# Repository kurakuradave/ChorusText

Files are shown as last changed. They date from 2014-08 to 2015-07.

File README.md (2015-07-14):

ChorusText
==========

What is ChorusText?
ChorusText is a text editor. But it's a special kind of text editor, the user doesn't need to have eyesight to do text editing using ChorusText. 

On the surface of the device, there are three physical sliders  that the user can reach out to at any time.

Changing the position of the slider would cause the system to pull out the corresponding part of the text and speaks the content out loud, using text-to-speech.

So changing the position of the line slider's knob from top to bottom will result in the system reading the text progressively line by line.

And changing the position of the word slider knob from left to right will result in the system reading the words in the current line, progressively word by word.

And likewise, changing the position of the character slider knob from left to right will result in the system spelling the letters of the current word, in the current line, progressively letter by letter.

This way, the user can read the text he's working on with ease, and can drill down to the level of characters effortlessly, for example, when spell-checking.

Furthermore, as the user types, the sliders continuously reposition themselves to physically manifest the latest state of the text and where the user is in the text.

If he adds two more characters to the current word, the character slider would move two steps to the right.
 If he adds three words to the line, the word slider would move three steps to the right.
Deleting the current line would make the line slider to move one step up, and so on.

The cursor is no longer an abstract blinking thing, that only lives inside the monitor, where the only way to locate its position is by means of eyesight. 

It is now physically manifested by the three sliders.

Simply reach out to the sliders with your hand and listen, the text is immediately accessible and navigable – no eyesight required.

Installing Node.js on pcDuino / Raspberry Pi
--------------------------------------------

1. On the pcDuino (or the Pi), open the terminal and execute:
$ wget http://nodejs.org/dist/v0.10.24/node-v0.10.24-linux-arm-pi.tar.gz
$ tar -xzvf node-v0.10.24-linux-arm-pi.tar-gz
$ sudo mv node-v0.10.24-linux-arm-pi /opt/node/

2. After that, test Node.js by:
$ /opt/node/bin/node
And if everything's okay, you'll get a ">" prompt. Simply hit Ctrl+C to quit.

Nodejs.org provides built binaries for the Raspberry Pi, which also works with pcDuino v1 or pcDuino3. There's no need to compile from source anymore, we simply need to download, extract and place it in a good location (in this case /opt/node/)
ChorusText is currently developed on Node version v0.10.24.

Chorus Text Client
------------------
1. Connect the pcDuino/Raspberry Pi to your wifi network and plug the Arduino to the pcDuino/Pi's USB port
2. SSH into the pcDuino/Pi, navigate to ChorusTextClient/ folder and execute: 
   $ sudo /opt/node/bin/node ChorusTextClient.js
3. Access the device by opening a web browser in any machine connected to the same wifi network as the pcDuino/Pi, and then go to it's hostname and at port 3000. For example: "http://pcduinobox:3000/" if the hostname for the SBC is pcduinobox ( or try its full IP if it doesnt work ).
4. To import text, go to http://pcduinobox:3000/import
5. To read text, go to http://pcduinobox:3000/read
6. To adjust settings, go to http://pcduinobox:3000/settings
7. To type, make sure the terminal window from which you launched the ChorusTextClient.js with node is in focus before you start typing. It is tied to the standard input on that terminal window so if the window is out of focus, ChorusTextClient can't pick up the keystrokes.

Repository Structure
--------------------

* Code for the Arduino is located in /arduino/
* Code for node client is located in /ChorusTextClient/
* Code for node server is located in /node-server/ (not yet)
* Hardware related items such as laser-cutting design files, wiring guide, list of components used, datasheets, etc are located in /hardware/

Got Questions?
--------------

Don't hesitate to email me :)

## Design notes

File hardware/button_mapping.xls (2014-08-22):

BUTTON MAPPING – ChorusText Board v0.17082014
BIN | LINE | WORD | CHAR | DEC
1 | Go Top | Go Top | Go Top | 1
10 | Scroll Up | Scroll Up | Scroll Up | 2
100 | Scroll Down | Scroll Down | Scroll Down | 4
1000 | Go Botto | Go Botto | Go Botto | 8
10000 | NA | FringeTop | DialLeft | 16
100000 | NA | FringeBottom | DialRight | 32
1000000 | NA | NA | NA | 64
10000000 | NA | NA | NA | 128

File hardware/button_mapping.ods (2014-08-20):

BUTTON MAPPING – ChorusText Board v0.17082014
BIN | LINE | WORD | CHAR | DEC
1 | Go Top | Go Bottom | Go Bottom | 1
10 | Scroll Up | Scroll Down | Scroll Down | 2
100 | Scroll Down | Scroll Up | Scroll Up | 4
1000 | Go Botto | Go Top | Go Top | 8
10000 | NA | FringeTop | DialLeft | 16
100000 | NA | FringeBottom | DialRight | 32
1000000 | NA | NA | NA | 64
10000000 | NA | NA | NA | 128

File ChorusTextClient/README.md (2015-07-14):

# ChorusTextClient

ChorusTextClient is the app to launch on the device. It is a Node.js application that handles communication with the Arduino, listens for keyboard keypresses, initiates text-to-speech, and serves the web-interface ( for text import, reading and settings ).

To run:
$ sudo /opt/node/bin/node ChorusTextClient.js

Replace the path to node according to your system, sudo is needed for the Arduino communication.

## Diagram
```

+-------------------------------------------------------------------+         +-------------------+
| ChorusText Device ( Client )                                      |         | ChorusText Server | 
|                                                                   |         |                   |
|               +-------------------------------------------------+ |         |  ( Coming Soon )  |
|               |  pcDuino                                        | |         |                   |
|               |                                                 | |         +-------------------+
|               |  +-----------------+                            | |
|               |  | ChorusSpeech.js |                            | |
|               |  |                 |                            | |
|               |  | spawn Text-to-  |                            | |
|               |  | speech child    |                            | |          
|               |  | processes       |                            | |          
|               |  +-----------------+                            | |          
|               |           |                                     | |         
|   /-------\   |  +-------------------+       +---------------+  | |          
|   |Arduino|   |  |ChorusTextClient.js|-------| Web Interface |  | |          
|   |       <---+-->                   |       |               |  | |
|   |sensors|   |  | main app          |___    | serves pages: |  | |     +------------------------+
|   |motors |   |  +-------------------+   \   | import, read, <--+-+--+  |  Tablet/Phone/Desktop  |
|   \-------/   |           |              |   | settings      |  | |  |  |                        | 
|               |  +-------------------+   |   +---------------+  | |  +--> Web-browser            |
|               |  | ChorusDocument.js |   |                      | |     |                        |
|               |  |                   |   |  +-----------------+ | |  +--> Other apps (Orca/iBus) |
|               |  | updates:          |   \__| API for Text    <-+-+--+  +------------------------+
|               |  | text content      |      | Import / Export | | |
|               |  | cursor position   |      +-----------------+ | |
|               |  +-------------------+                          | |
|               |                                                 | |
|               +-------------------------------------------------+ |
|                                                                   |
+-------------------------------------------------------------------+

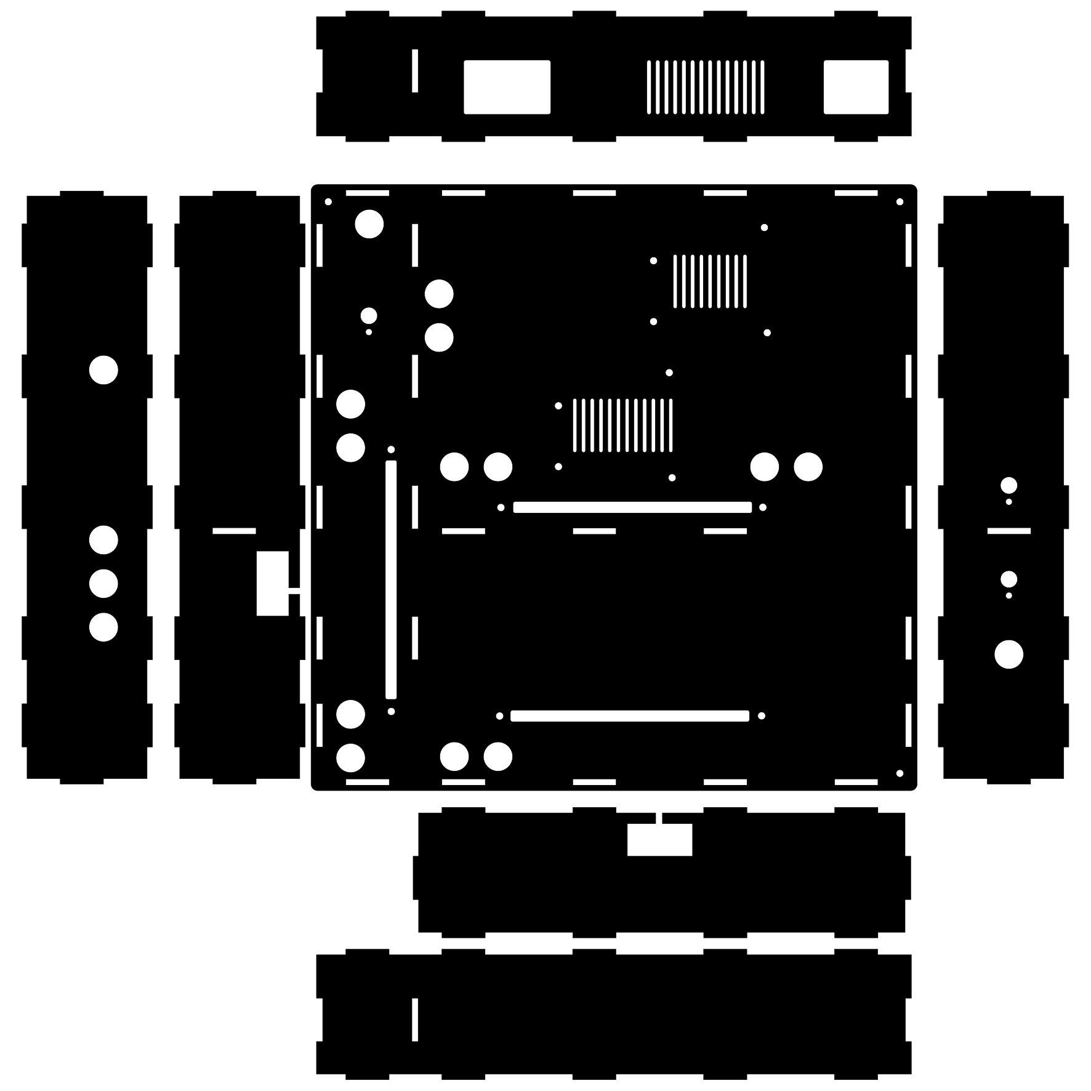
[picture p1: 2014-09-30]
hardware/board-design/panelmount-buttons/more_features_coming.png

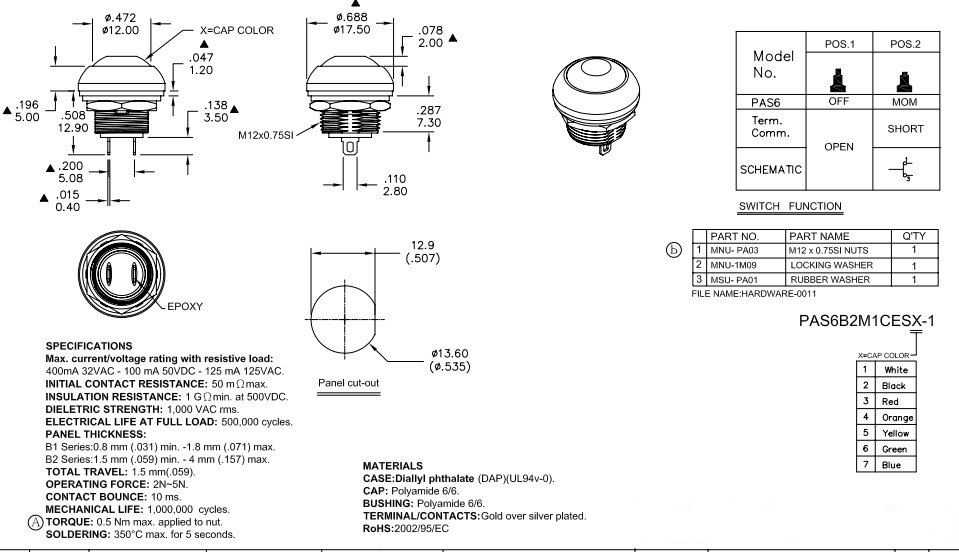
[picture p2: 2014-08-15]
hardware/ref/12mm Domed Push Button Pack.jpg

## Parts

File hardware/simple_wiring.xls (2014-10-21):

No | COMPONENT | CONNECTOR | CONNECT_TO
1 | Line Slide Potentiometer | 1 | Arduino GND pin
 |  | 2 | Arduino A0 pin
 |  | 3 | Arduino 5V pin
 |  | 1' | not used
 |  | 2' | not used
 |  | 3' | not used
 |  | T | not used
 |  | A | MotorShield MotorPort 1, INNER screw terminal
 |  | B | MotorShield MotorPort 1, OUTER screw terminal
2 | Word Slide Potentiometer | 1 | Arduino GND pin
 |  | 2 | Arduino A1 pin
 |  | 3 | Arduino 5V pin
 |  | 1' | not used
 |  | 2' | not used
 |  | 3' | not used
 |  | T | not used
 |  | A | MotorShield MotorPort 2,INNER screw terminal
 |  | B | MotorShield MotorPort 2,OUTER screw terminal
3 | Char Slide Potentiometer | 1 | Arduino GND pin
 |  | 2 | Arduino A2 pin
 |  | 3 | Arduino 5V pin
 |  | 1' | not used
 |  | 2' | not used
 |  | 3' | not used
 |  | T | not used
 |  | A | MotorShield MotorPort 3,INNER screw terminal
 |  | B | MotorShield MotorPort 3,OUTER screw terminal
4 | Focus Dial | left connector | Arduino 5V pin
 | Orient the motorized rotary | center connector | Arduino A3 pin
 | potentiometer like so: | right connector | Arduino GND pin
 | - rotating rod facing up | left motor terminal | Motor Shield MotorPort4, OUTER screw terminal
 | - motor facing down | right motor terminal | Motor Shield MotorPort 4, INNER screw terminal
 | - six connectors facing you

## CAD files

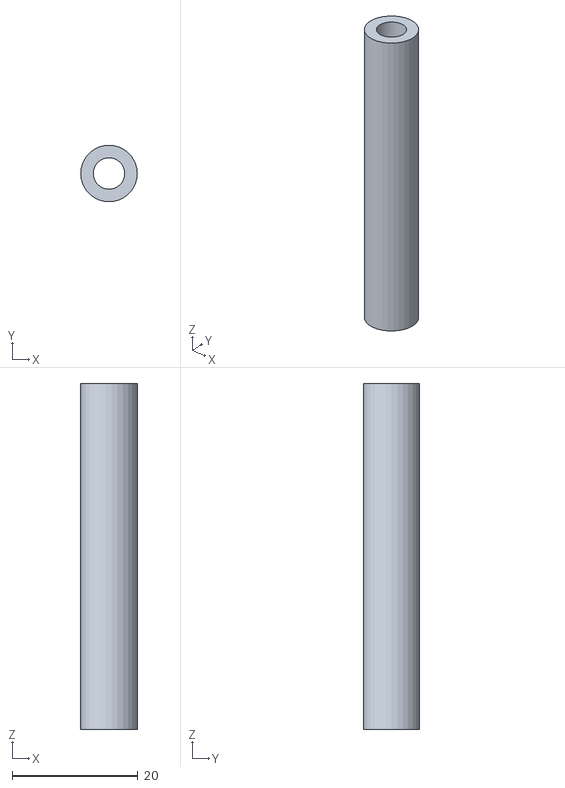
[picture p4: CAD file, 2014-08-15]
hardware/3Dprinting/tubeA.stl
9.00 x 8.95 x 55.0

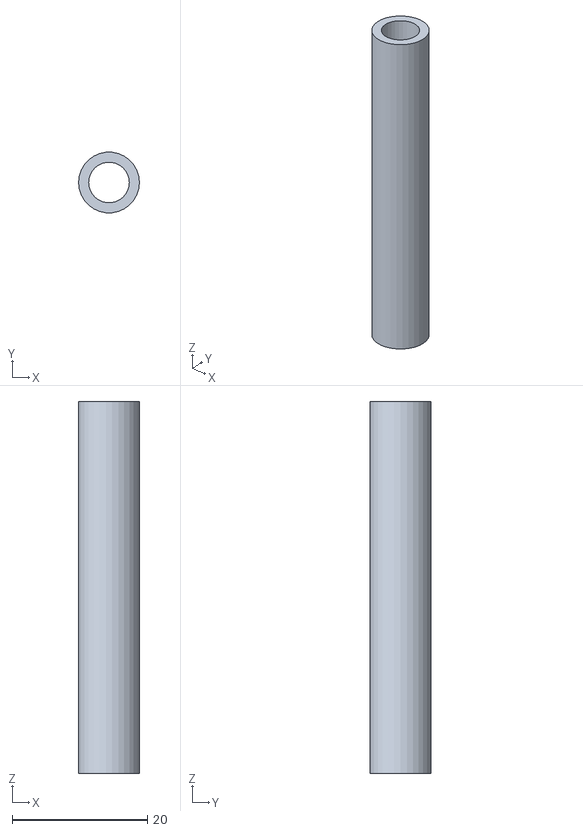
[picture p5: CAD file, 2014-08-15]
hardware/3Dprinting/tubeB.stl
9.00 x 8.95 x 55.0

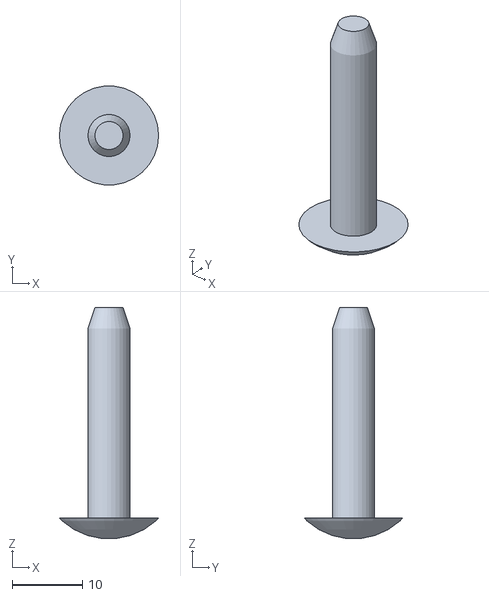
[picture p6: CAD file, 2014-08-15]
hardware/3Dprinting/spokeB.stl
14.2 x 14.1 x 32.9

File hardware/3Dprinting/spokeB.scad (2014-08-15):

$fn=30;

translate([0,0,26]) {
	cylinder(3,3,2);
}

translate([0,0,-2]) {
    cylinder(r=3,h=28);
}

translate( [0,0,6] ) {
	difference() {
  		  sphere( r=10 );
    		translate([0,0,-7]){
      	  cylinder(r=15,h=17); 
    		}
	}
}

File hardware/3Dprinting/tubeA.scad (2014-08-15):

$fn=30;
difference() {
    cylinder( r=4.5, h=55 );
    cylinder( r=2.5, h=60);
};

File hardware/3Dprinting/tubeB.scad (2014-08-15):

$fn=30;
difference() {
    cylinder( r=4.5, h=55 );
    cylinder( r=3, h=60);
};

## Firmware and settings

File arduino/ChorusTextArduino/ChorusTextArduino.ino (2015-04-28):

/*-----------------------------------------------------------------------------\
|                                                                              |
|    ChorusTextArduino - Arduino program for ChorusText Open Assistive Device  |
|    Copyright (C) 2014  David Effendi                                         |
|    email: kurakuradave@gmail.com                                             |
|                                                                              |
|    This program is free software: you can redistribute it and/or modify      |
|    it under the terms of the GNU General Public License as published by      |
|    the Free Software Foundation, either version 3 of the License, or         |
|    (at your option) any later version.                                       |
|                                                                              |
|    This program is distributed in the hope that it will be useful,           |
|    but WITHOUT ANY WARRANTY; without even the implied warranty of            |
|    MERCHANTABILITY or FITNESS FOR A PARTICULAR PURPOSE.  See the             |
|    GNU General Public License for more details.                              |
|                                                                              |
|    You should have received a copy of the GNU General Public License         |
|    along with this program.  If not, see <http://www.gnu.org/licenses/>.     |
|                                                                              |
\-----------------------------------------------------------------------------*/


/*=========================================\\
|| For use with Adafruit Motor Shield v2   ||
|| For wiring on the shield, please refer ||
|| to /hardware/simple_wiring.xls file.   ||
\\========================================*/

#include <Wire.h>
#include <PID_v1.h>
#include <Adafruit_ADS1015.h>
#include <Adafruit_MotorShield.h>
#include "utility/Adafruit_PWMServoDriver.h"
#include <PID_v1.h>

/*========================================================
||  class for manipulating/controlling the sliders      ||
||  instantiate one for each slider                     ||
========================================================*/

class CSlider {
 
  private:
        int _pin;                     // the pin number on the Arduino that this slider's pot is hooked up to
        const byte PID_ERROR_MARGIN;  // tolerable overshoot or undershoot distance from the target
        Adafruit_DCMotor *_motor;     // which motor port (1/2/3/4) on the Adafruit Motor Shield is this slider hooked up to
             
        int _slideDirection;
        bool _isMoving;               // true if slider has not yet reached its target position +/- PID_ERROR_MARGIN 
        PID _sliderPID;
        byte _sliderKind;             // 1 = Line, 2 = Word, 3 = Char
        bool _isSlotChanged;          // true if knob is resting on a different slot. A slider is divided into ten slots or regions each with an interval of 100, last slot has interval of 124, total of all slots is 1024 which is the full range of Arduino analog pin reading, and tied to full potentiometer track.
        byte _curSlot, _oldSlot;      // current and old slot position values
        
    public:
        CSlider( byte sliderKind, int pin, Adafruit_DCMotor *motorAddress ) :
            _sliderKind( sliderKind ),
            _pin( pin ),
            PID_ERROR_MARGIN( 15 ),
            _motor( motorAddress ),
            _slideDirection( 1 ),
            _isMoving( true ),
            _isSlotChanged( false ),
            _input( 0 ), 
            _inputOld( 0 ), 
            _curSlot( 0 ),
            _oldSlot( 0 ),
            _setpoint( 50 ), 
            _output( 0 ),
            _sliderPID( &_input, &_output, &_setpoint,2,0.025,0.25, DIRECT )
        {
        } 
        double _input, _inputOld, _setpoint, _output;
        void slideToTarget( int theValue );
        byte toSlot( double theInput );
        byte getSlot();
        void processTactile();
        void run();
        void showStatus();
        void initialize();
        void readSliderValue();
        bool getIsMoving();
        bool getIsSlotChanged();
        void slide();        

    
}; // end class header CSlider

/*============================================================\\
||   Implementation of the methods in class CSlider           ||
\\============================================================*/ 

void CSlider::initialize() {
  //Serial.println( "setting _sliderPID to AUTOMATIC" );;
  _sliderPID.SetMode(AUTOMATIC);
  //Serial.println( "DONE!" ); 
} // end initialize()




void CSlider::showStatus() {
   Serial.print( "I am a slider of kind: " );
   if( _sliderKind == 1 )
       Serial.println( "LINE" );
   else if( _sliderKind == 2 )
       Serial.println( "WORD" );
   else
       Serial.println( "CHAR" );
   Serial.print( "_pin is: " ); 
   Serial.println( _pin );
   Serial.print( "PID_ERRO_MARGIN is: " );
   Serial.println( PID_ERROR_MARGIN );
   Serial.print( "_slideDirection is: " );
   Serial.println( _slideDirection );
   Serial.print( "_isMoving is: " );
   Serial.println( _isMoving );
   Serial.println( "_input, _inputOld, _setpoint and _output are: " );
   Serial.println( _input ); 
   Serial.println( _inputOld );
   Serial.println(  _setpoint );
   Serial.println(  _output );
} // end showStatus()




void CSlider::slideToTarget( int theValue ) {
// this will assign a new target for the slider to move to, as well as set it in motion
  _setpoint = theValue;
  _inputOld = theValue; // advance _inputOld to target value, otherwise a reset dependants will trigger when line/word sliders arrive at target value.
  _curSlot = toSlot( theValue );
  _oldSlot = _curSlot; // advance _oldSlot
  _isSlotChanged = false; // because we're manually driving the slider here
  _isMoving = true;
} // end slideToTarget()




byte CSlider::toSlot( double theInput ) {
//given a raw analog read value, determine which slot that slider is on and return the value 
  byte ret = floor( theInput / 100 );
  if( ret > 9 )
    ret = 9;
  return ret;
} // end toSlot()




byte CSlider::getSlot() {
  return toSlot( _input );
} // end getSlot()




void CSlider::processTactile() {
// this is for handling changes to the knob's position that is caused by user tactile input / physically dragging the knob
// it basically checks whether there's a change in knob's location
// if yes, prepare a String message to send to the RPi
// send it
// then memorize knob's new position
  _curSlot = toSlot( _input );
  _oldSlot = toSlot( _inputOld );

  if( _curSlot != _oldSlot ) {
    _isSlotChanged = true;
    String myType = "c";
    if( _sliderKind == 1 )
      myType = "l";
    else if( _sliderKind == 2 )
      myType = "w";
    String msg = String( "{\"r\":{\"" + myType + "\":\"" ) + String( _curSlot ) + String( "\"}}" );
    Serial.println( msg ); 
  } else {
    _isSlotChanged = false;
  } 
  _inputOld = _input;
} // end processTactile()




bool CSlider::getIsMoving() {
  return _isMoving;
} // end getIsMoving()




bool CSlider::getIsSlotChanged() {
  return _isSlotChanged;
} // end getIsSlotChanged()



// NOT USED NOW, to be implemented after knowing how to refer to the main sketch, or 
// refer to an arraylist of dependants
void CSlider::run() {
  /*
  readSliderValue();
  if( getIsMoving() )  
    slide();
  else 
    processTactile();
  if( getIsSlotChanged() )
    // slide dependants to zero
*/
} // end run()



// private methods

void CSlider::readSliderValue(){
  // if sliders are placed to slide from 0 to 1024 from left to right OR up to down, use
  //return( analogRead( _pin ) );

  // otherwise use
  double rawInput = (1024 - analogRead( _pin ));
  if( abs( rawInput - _input ) > 5 ) // filter out noise from very slight changes
    _input = rawInput; 
} // end readSliderValue()




void CSlider::slide() {

    // correction for bidirectional movement
    if( _slideDirection == -1 ) {
      _input = 1024-_input; 
    }

    if( _input - _setpoint > PID_ERROR_MARGIN ) {
      // overshot, reverse direction
      _input = 1024-_input;
      _setpoint = 1024-_setpoint;
      _slideDirection = -1 * _slideDirection;
    }

    if( abs( _input - _setpoint ) > PID_ERROR_MARGIN ) { // target not yet reached
      _sliderPID.Compute();
      if( _output > 220 )    // upper cap to sliding speed
        _output = 220;
      if( _output < 200 )
        _output = 200;
      
      _motor->setSpeed( _output );
      if( _slideDirection == -1 ) {
        _motor->run( BACKWARD ); // reverse wiring on the motor shield if it slide to wrong direction
      }  else { 
        _motor->run( FORWARD ); 
      }
      delay( 10 );
      _motor->run(RELEASE );
    } else { // target reached
      _isMoving = false;
      if( _slideDirection == -1 ) { // if stopping after a -1 dir, then normalize
        _setpoint = 1024 - _setpoint;  
        _input = 1024 - _input;
      }
      _slideDirection = 1;
      //showStatus();    // uncomment to check stuff
    }
    _isSlotChanged = false;

} // end slide()
       


/*========================================================
||  class for manipulating/controlling the dial         |
========================================================*/

class CDial {
 
  private:
        int _pin;                     // the pin number on the  that this dial's pot is hooked up to
        const byte PID_ERROR_MARGIN;  // tolerable overshoot or undershoot distance from the target
        Adafruit_DCMotor *_motor;     // which motor port (1/2/3/4) on the Adafruit Motor Shield is this dial hooked up to
             
        int _rotateDirection;
        bool _isMoving;               // true if dial has not yet reached its target position +/- PID_ERROR_MARGIN 
        PID _dialPID;
        bool _isSlotChanged;          // true if dial is pointing on a different slot. A dial is divided into five slots or regions each with an interval of 200, last slot has interval of 224, total of all slots is 1024 which is the full range of Arduino analog pin reading, and tied to full potentiometer track.
        byte _curSlot, _oldSlot;       // current and old slot position values
   
    public:
        CDial( int pin, Adafruit_DCMotor *motorAddress ) :
            _pin( pin ),
            PID_ERROR_MARGIN( 15 ),
            _motor( motorAddress ),
            _rotateDirection( 1 ),
            _isMoving( true ),
            _isSlotChanged( false ),
            _input( 512 ), 
            _inputOld( 512 ), 
            _curSlot( 0 ),
            _oldSlot( 0 ),
            _setpoint( 512 ), 
            _output( 0 ),
            _dialPID( &_input, &_output, &_setpoint,2,0.025,0.25, DIRECT )
        {
        } 
        double _input, _inputOld, _setpoint, _output;
        void rotateToTarget( int theValue );
        byte toSlot( double theInput );
        byte getSlot();
        void processTactile();
        void run();
        void showStatus();
        void initialize();
        void readDialValue();
        bool getIsMoving();
        bool getIsSlotChanged();
        void rotate();        

    
}; // end class header CDial

/*============================================================\\
||   Implementation of the methods in class CDial             ||
\\============================================================*/ 

void CDial::initialize() {
  //Serial.println( "setting _dialPID to AUTOMATIC" );;
  _dialPID.SetMode(AUTOMATIC);
  //Serial.println( "DONE!" ); 
} // end initialize()




void CDial::showStatus() {
   Serial.print( "I am a DIAL " );
   Serial.print( "_pin is: " ); 
   Serial.println( _pin );
   Serial.print( "PID_ERRO_MARGIN is: " );
   Serial.println( PID_ERROR_MARGIN );
   Serial.print( "_rotateDirection is: " );
   Serial.println( _rotateDirection );
   Serial.print( "_isMoving is: " );
   Serial.println( _isMoving );
   Serial.println( "_input, _inputOld, _setpoint and _output are: " );
   Serial.println( _input ); 
   Serial.println( _inputOld );
   Serial.println(  _setpoint );
   Serial.println(  _output );
} // end showStatus()




void CDial::rotateToTarget( int theValue ) {
// this will assign a new target for the dial to move to, as well as set it in motion
  _setpoint = theValue;
  _input = toSlot( theValue );
  _inputOld = _input;
  _isMoving = true;
} // end rotateToTarget()




byte CDial::toSlot( double theInput ) {
//given a raw analog read value, determine which slot that dial is on and return the value 
  byte ret = floor( theInput / 200 );
  if( ret > 4 )
    ret = 4;
  return ret;
} // end toSlot()




byte CDial::getSlot() {
  return toSlot( _input );
} // end getSlot()




void CDial::processTactile() {
// this is for handling changes to the knob's position that is caused by user tactile input / physically rotating the knob
// it basically checks whether there's a change in knob's location
// if yes, prepare a String message to send to the RPi
// send it
// then memorize knob's new position
  _curSlot = toSlot( _input );
  _oldSlot = toSlot( _inputOld );

  if( _curSlot != _oldSlot ) {
    _isSlotChanged = true;
    String myType = "d";
    String msg = String( "{\"t\":{\"" + myType + "\":\"" ) + String( _curSlot ) + String( "\" } }" ); // turn dial x
    // _curSlot 0/1/2/3/4 is settings/location/main/chat/find
    Serial.println( msg ); 
  } else {
    _isSlotChanged = false;
  } 
  _inputOld = _input;
} // end processTactile()
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
void loop() {
  // process incoming Serial data
  if( Serial.available() > 0 ) {
    if( queryType != "" ) { // expecting a numeric return from client
      incomingNum = Serial.parseInt();
      if( queryType == "line" ){
        lineSlider.slideToTarget( incomingNum * 100 + 50 );  
      } else if ( queryType == "word" ){
        wordSlider.slideToTarget( incomingNum * 100 + 50);
      } else if( queryType == "char" ) {
        charSlider.slideToTarget( incomingNum * 100 + 50 );
      }
      queryType = "";
      incomingNum = 0;
    } else { // default, parseString
      incomingString = Serial.readString();
      if( incomingString.substring( 0, 2 ) == "MS" ) { // Move Sliders
        // format is always MS-X-X-X where Xs are slot numbers ( single digit ) for line, word and char, respectively
        int cLine = incomingString.charAt( 3 ) - '0';
        int cWord = incomingString.charAt( 5 ) - '0';
        int cChar = incomingString.charAt( 7 ) - '0'; 
        
        lineSlider.slideToTarget( cLine * 100 + 50 );
        wordSlider.slideToTarget( cWord * 100 + 50 );
        charSlider.slideToTarget( cChar * 100 + 50 );
        incomingString = "";
      }
    }
  }

  // process shift-in registers
  digitalWrite(latchPin,1);
  delayMicroseconds(20);
  digitalWrite(latchPin,0);
  // read in the values
  switchVar1 = shiftIn(dataPin, clockPin);
  switchVar2 = shiftIn(dataPin, clockPin);
  switchVar3 = shiftIn(dataPin, clockPin);

  // debug 
  /*
  if( switchVar1 != 0 ) {
  Serial.println( switchVar1 );
  }
    if( switchVar2 != 0 ) {
  Serial.println( switchVar2 );
  }
    if( switchVar3 != 0 ) {
  Serial.println( switchVar3 );
  }
  */
  if( switchVar1 != 0 && oldSwitchVar1 == 0 ) {
    oldSwitchVar1 = switchVar1;
    switch( switchVar1 ) {
      case 1: // go top
        lineSlider.slideToTarget( 50 );
        wordSlider.slideToTarget( 50 );
        charSlider.slideToTarget( 50 );
        Serial.println( "{\"j\":{\"l\":\"t\"}}" ); // jump line top
      break;
      case 2: // scroll up
        lineSlider.slideToTarget( 950 );
        wordSlider.slideToTarget( 50 );
        charSlider.slideToTarget( 50 );
        Serial.println( "{\"j\":{\"l\":\"u\"}}" ); // jump line scrollup
        queryType = "line";
        Serial.println( "{\"q\":\"l\"}" ); // query line
      break;
      case 4: // scroll down
        lineSlider.slideToTarget( 50 );
        wordSlider.slideToTarget( 50 );
        charSlider.slideToTarget( 50 );
        Serial.println( "{\"j\":{\"l\":\"d\"}}" ); // jump line scrolldown
      break;
      case 8: // go bottom
        lineSlider.slideToTarget( 950 );
        wordSlider.slideToTarget( 50 );
        charSlider.slideToTarget( 50 );
        Serial.println( "{\"j\":{\"l\":\"b\"}}" ); // jump line bottom
      break;
      case 16: // read all
        Serial.println( "{\"r\":\"a\"}" ); // read all
      break;
      case 32: // OCR
        Serial.println( "{\"o\":\"o\"}" ); // OCR
      break;
      case 64: // cycle language
        Serial.println( "{\"l\":\"c\"}" ); // language cycle
      break;
      case 128: // read current
        String msg = String( "{\"v\":{\"l\":" ) + String( lineSlider.getSlot() ) + String( "}}" ); //verify current line
        Serial.println( msg );
      break;
    }
  } else {
    if( switchVar1 == 0 ) {
      oldSwitchVar1 = 0;
    } 
  }
  
  if( switchVar2 != 0 && oldSwitchVar2 == 0 ) {
    oldSwitchVar2 = switchVar2;
    switch( switchVar2 ) {
      case 1: // go top
        wordSlider.slideToTarget( 50 );
        charSlider.slideToTarget( 50 );
        Serial.println( "{\"j\":{\"w\":\"t\"}}" ); // jump word top
      break;
      case 2: // scroll up
        wordSlider.slideToTarget( 950 );
        charSlider.slideToTarget( 50 );
        Serial.println( "{\"j\":{\"w\":\"u\"}}" ); // jump word scrollup
        queryType = "word";
        Serial.println( "{\"q\":\"w\"}" ); // query word
      break;
      case 4: // scroll down
        wordSlider.slideToTarget( 50 );
        charSlider.slideToTarget( 50 );
        Serial.println( "{\"j\":{\"w\":\"d\"}}" ); // jump word scrolldown
      break;
      case 8: // go bottom
        wordSlider.slideToTarget( 950 );
        charSlider.slideToTarget( 50 );
        Serial.println( "{\"j\":{\"w\":\"b\"}}" ); // jump word bottom
      break;
      case 128: // read current
        String msg = String( "{\"v\":{\"w\":" ) + String( wordSlider.getSlot() ) + String( "}}" ); // verify current word
        Serial.println( msg );
      break;
    }
  } else {
    if( switchVar2 == 0 ) {
      oldSwitchVar2 = 0;
    } 
  }
  
  if( switchVar3 != 0 && oldSwitchVar3 == 0 ) {
    oldSwitchVar3 = switchVar3;
    switch( switchVar3 ) {
      case 1: // go top
        charSlider.slideToTarget( 50 );
        Serial.println( "{\"j\":{\"c\":\"t\"}}" ); // jump char top
      break;
      case 2: // scroll up
        charSlider.slideToTarget( 950 );
        Serial.println( "{\"j\":{\"c\":\"u\"}}" ); // jump char scrollup
        queryType = "char";
        Serial.println( "{\"q\":\"c\"}" ); // query char
      break;
      case 4: // scroll down
        charSlider.slideToTarget( 50 );
        Serial.println( "{\"j\":{\"c\":\"d\"}}" ); // jump char scrolldown
      break;
      case 8: // go bottom
        charSlider.slideToTarget( 950 );
        Serial.println( "{\"j\":{\"c\":\"b\"}}" ); // jump char bottom
      break;
      case 16: // dialbutton left
        if( rotDial.getSlot() == 0 ) {   // settings  
          Serial.println( "{\"m\":\"u\"}" );    // menu up
        } 
      break;
      case 32: // dialbutton right
        if( rotDial.getSlot() == 0 ) { // settings
          Serial.println( "{\"m\":\"d\"}" );    // menu down
        }
      break;        
      case 128: // read current
        String msg = String( "{\"v\":{\"c\":" ) + String( charSlider.getSlot() ) + String( "}}" ); // verify current char
        Serial.println( msg );
      break;      
    }
  } else {
    if( switchVar3 == 0 ) {
      oldSwitchVar3 = 0;
    } 
  }
  
   
   int16_t adc2, adc3;
   adc2 = ads1115.readADC_SingleEnded(2);
   adc3 = ads1115.readADC_SingleEnded(3);
   
   updateSpeechRate( "sg", adc2, old_adc2, old_sg );
   updateSpeechRate( "sc", adc3, old_adc3, old_sc );
   
   
  // process Sliders
  
  rotDial.readDialValue();
  if( rotDial.getIsMoving() ){  
    rotDial.rotate();
  }
  else
    rotDial.processTactile();

  // bad code here.. the intention is to move these into CSlider.run() one day
// TO Implement
// the line CSlider would need reference to the word and char CSliders, 
// coz line needs to be able to slide word and char back to 0th slot
// ditto word CSlider need reference for char CSlider
// but char CSlider doesn't need any reference

//==================
// first, do line slider routines
// then, do word slider routines
// last, do char slider routines
//==================

//=================
// line slider routines
//=================
  lineSlider.readSliderValue();
  if( lineSlider.getIsMoving() ) { // this means that, in the current loop() cycle the slider is in motion - trying to complete its travel to the target position, which was set by slideToTarget() in a previous loop() cycle.
// do not disrupt it, just let it finish running its course
    lineSlider.slide();
  }
  else 
    lineSlider.processTactile(); // only do this if slider has reached target +/- pid error margin around target position
  // below should be refactored and placed inside processTactile()
  if( lineSlider.getIsSlotChanged() ) {  // knob is now on a different slot
    // slide dependants to their 0th slot or initial position
    if( wordSlider. getSlot() != 0 )
      wordSlider.slideToTarget( 50 );
    if( charSlider.getSlot() != 0 )
      charSlider.slideToTarget( 50 );
  }

//==================
// word slider routines
//==================
  wordSlider.readSliderValue();
  if( wordSlider.getIsMoving() ) {  
    wordSlider.slide();
  }
  else 
    wordSlider.processTactile();
  // below should be refactord to be inside processTactile()
  if( wordSlider.getIsSlotChanged() ) {
    // slide dependants to their 0th slot
    if( charSlider.getSlot() != 0 )
      charSlider.slideToTarget( 50 );
  }


//==================
// char slider routines
//==================
  charSlider.readSliderValue();
  if( charSlider.getIsMoving() ) {
    charSlider.slide();
  }
  else 
    charSlider.processTactile();
  // charSlider doesnt have a dependant

} // end loop()
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

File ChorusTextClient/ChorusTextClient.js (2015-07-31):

/*-----------------------------------------------------------------------------\
|                                                                              |
|    ChorusTextClient - Client program for ChorusText Open Assistive Device    |
|    Copyright (C) 2014  David Effendi                                         |
|    email: kurakuradave@gmail.com                                             |
|                                                                              |
|    This program is free software: you can redistribute it and/or modify      |
|    it under the terms of the GNU General Public License as published by      |
|    the Free Software Foundation, either version 3 of the License, or         |
|    (at your option) any later version.                                       |
|                                                                              |
|    This program is distributed in the hope that it will be useful,           |
|    but WITHOUT ANY WARRANTY; without even the implied warranty of            |
|    MERCHANTABILITY or FITNESS FOR A PARTICULAR PURPOSE.  See the             |
|    GNU General Public License for more details.                              |
|                                                                              |
|    You should have received a copy of the GNU General Public License         |
|    along with this program.  If not, see <http://www.gnu.org/licenses/>.     |
|                                                                              |
\-----------------------------------------------------------------------------*/


// ==================================================
// setup for Arduino communication
// ==================================================
var serialPort = require("serialport");
var cFocus = 2;
var ChorusSpeech = require( './ChorusSpeech.js' );
var cs = new ChorusSpeech();
var CD = require( './ChorusDocument.js' );
var cd = new CD();
var SerialPort = serialPort.SerialPort; // localize object constructor
var cfg = require( './ChorusTextConfig.js' );
var fullServerAddress = cfg.serverAddress + ":" + cfg.serverPort;
var reqq = require( 'request' );
var ccdocuID = "";
var userID = cfg.devID;
var devNum = cfg.devNum;

// ========================================================
// setup for the Web Interface Server - Express & Socket.io
// ========================================================
var express = require('express');
var path = require('path');
var favicon = require('static-favicon');
var logger = require('morgan');
var cookieParser = require('cookie-parser');
var bodyParser = require('body-parser');

var routes = require('./routes/index');
var users = require('./routes/users');
var gnome = require( './routes/gnome' );
gnome.setCD( cd );

var app = express();

// mounting socket.io
var http = require('http').createServer(app).listen(3000);
var io = require( 'socket.io' )( http );

// view engine setup
app.set('views', path.join(__dirname, 'views'));
app.set('view engine', 'jade');

app.use(favicon());
app.use(logger('dev'));
app.use(bodyParser.json());
app.use(bodyParser.urlencoded());
app.use(cookieParser());
app.use(express.static(path.join(__dirname, 'public')));

app.use('/', routes);
app.use('/users', users);
app.use( '/gnome', gnome );

/// catch 404 and forward to error handler
app.use(function(req, res, next) {
    var err = new Error('Not Found');
    err.status = 404;
    next(err);
});

/// error handlers

// development error handler
// will print stacktrace
if (app.get('env') === 'development') {
    app.use(function(err, req, res, next) {
        res.status(err.status || 500);
        res.render('error', {
            message: err.message,
            error: err
        });
    });
}

// production error handler
// no stacktraces leaked to user
app.use(function(err, req, res, next) {
    res.status(err.status || 500);
    res.render('error', {
        message: err.message,
        error: {}
    });
});




//=============================================================
// socket.io application logic (RUNNING AS CLIENT TO WEBSERVER)
//=============================================================
// socket.io stuff
var ioClient = require( 'socket.io-client' );
var socketClient = ioClient.connect(fullServerAddress, {reconnect: true});

socketClient.on('cnected2ssn', function( data ) { 
     console.log( "ChorusText device connected to server via socket! " ); 
     console.log( data.msg );
});

socketClient.on( 'newUserJoined', function( data ) {  
    console.log( "A new user just joined: " + data.userID );
} );




// =================================================================
// socket.io application logic (RUNNING AS SERVER FOR OTHER DEVICES)
// =================================================================

var importedRawText = "";
io.on('connection', function(socket){
      console.log('a user connected');

      socket.on( 'initForImport', function( data ) {  
          console.log( "<<<<<<<<<< received initForImport" );
          console.log( "joining room import" );
          socket.join( "import" );
      } );

      socket.on( 'importText', function( itObj ) {
        console.log( "<<<<<<<<<< Received new text: " );
        console.log( itObj.rawText );
        importedRawText = itObj.rawText;
        cd.setVisualText( itObj.rawText );
        cd.parseToCTDocu();
        cs.sys_say( "text_imported" );
        //send update to sockets in room import
        var ifrObj = { 'lines' : cd.getLines(), 
                       'cursor' : cd.getCursor()
        }; 
        console.log( ">>>>>>>>>> emitting initForRead" );
        io.to( "read" ).emit( 'initForRead', ifrObj );
      } );

      socket.on( 'initForRead', function( data ) { 
          console.log( "<<<<<<<<<< received initForRead" );
          console.log( "joining room read" );
        socket.join( "read" );
        var ifrObj = { 'lines' : cd.getLines(), 
                       'cursor' : cd.getCursor()
        }; 
        console.log( ">>>>>>>>>> emitting initForRead" );
        io.to( "read" ).emit( 'initForRead', ifrObj );
      } ); 

      socket.on( 'initForSettings', function( data ) {  
          console.log( "<<<<<<<<<< received initForSettings" );
          console.log( "joining room settings" );
        socket.join( 'settings' );
        var ifsObj = { 'espeakSettings': cs.getSettings(), 'supportedLanguages' : cs.getSupportedLanguages() };
        console.log( ">>>>>>>>>> emitting initForSettings" );
        io.to( "settings" ).emit( 'initForSettings', ifsObj );
      } );  

      socket.on( 'applySettings', function( asObj ) { 
          console.log( "<<<<<<<<<< received applySettings" );
          console.log( "applying new settings" );
          cs.setRate( "general", asObj.rate );
          cs.setLanguage( asObj.lang );        
      } );

});
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

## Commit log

2014-03-03 fixed JSON output from Arduino
    [ChorusTextArduino.ino]
2014-05-03 Some more comments on Arduino code
2014-05-15 Tweaked Arduino code to support Adafruit Motor Shield v2
2014-05-15 added design files for laser cutting the board
2014-05-16 ChorusTextBoard .svg and .eps - shifted buttons for the rotary pot 15 mm lower to make some space for the user's finger
2014-05-16 ChorusTextBoard .svg and .eps - added anchoring hole for the rotary pot
2014-05-27 Added modularized version for the laser cut board
2014-05-29 updated ChorusTextBoard.svg and .eps to have same slot width with the modularized version
2014-05-29 Fixed screw holes accidentally went off alignment on the Frame center piece
2014-06-03 Added arduino code for controlling rotary dial
2014-06-25 Added basic Bootstrap, Express, Angular and Socket.IO to the Node-Client software
2014-07-03 Text imported from web interface now available in board
    web interface for reading - initforread loading done, next step is to implement real-time updating of web interface display as slider is physically moved
2014-07-04 ChorusTextPi - enlarged text display on /read now updates in real-time, in accordance with sliding of the physical knobs on the board
2014-07-08 ChorusTextPi - adding built serialport library for arm platform
2014-07-17 ChorusTextPi - bugfix for importing blank text to board
2014-08-04 hardware - adjusted board layout to use 12mm panelmount buttons
2014-08-05 hardware - board layout - added square layout
2014-08-07 hardware - board is now designed as a box instead of a surface plate
2014-08-07 hardware - board layout - added speech rate dial, volume dial, language cycle button and read whole page button
2014-08-14 hardware - added design files for tubes and spoke
    [spokeB.scad, spokeB.stl, tubeA.scad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]
2014-08-20 arduino - added experimental code for line scrolling buttons
    [button_mapping.ods, button_mapping.xls]
2014-08-22 arduino code - added code for 16 buttons
    ChorusTextClient - imlemented code for functionality of the 16 buttons plus minor bug fixes
    [button_mapping.xls]
2014-08-22 ChorusTextClient and arduino - fixed bug scrollup does not move the slider to correct location when knob position is within the first scope, or less than 10
    [ChorusTextArduino.ino, ChorusTextClient.js]
2014-08-28 fixed yet more typo
    [ChorusTextClient.js]
2014-09-15 fixed bug cursor out of scope when jumping to bottom line/word/char
    added updating of browser-displayed speechrate and selected language when user press buttons
    added filtering of slider movements when focus is not on main text area
    added focus switching
    added toggle language when focus is set to settings
    [ChorusTextArduino.ino, ChorusTextClient.js]
2014-10-21 arduino - code adapted for panelmount design
    ChorusTextClient - bug fixes, inserting new characters now work on display, next is to send update to arduino sliders
    [simple_wiring.xls]
2014-10-23 arduino - fixed bug slideToTarget() causes dependants to erroneously reset
    ChorusTextClient - now char insert is correctly manifested out in Arduino positioning of the 3 sliders
    [ChorusTextArduino.ino, ChorusTextClient.js]
2014-11-06 arduino - tweaked down sensitivity of the two speech rate dials
2014-11-27 ChorusTextClient - added auto detection of Arduino port name
2015-03-18 ChorusTextClient - bugfix for cycle languages via up button skips Chinese
    ChorusTextClient - Added try catch block to guard against invalid JSON strings from Arduino
    [ChorusTextClient.js]
2015-03-18 ChorusTextClient - replaced algorithm for physical manifestation of the changes in text with a new, faster, more robust algorithm (using digest cycle instead of promises). Code still needs some house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
    [ChorusTextClient.js]
2015-03-19 ChorusTextClient - code around insertion of new character tidied up
2015-03-19 ChorusTextClient - code around deletion of a character via backspace button tidied up
2015-03-27 Added FOSSASIA API file ChorusText-api.json
    ChorusTextClient - implemented insertion of new word and splitting of a word into two as a result of pressing Spacce key
2015-04-07 ChorusTextClient - fixe- fixed bug trailing space at end of tail following keypress of return
    ChorusTextClient - fixed bug slider misalighed with software cursor position following insertion of new line with index greater than 9
    [ChorusTextClient.js]
2015-04-08 ChorusTextClient - bug fixing for return keypress
    [ChorusTextClient.js]
2015-04-08 ChorusTextClient - various bug fixes
    [ChorusTextClient.js]
2015-04-27 ChorusTextClient - bugfixes for insertion/deletion of characters at wrong place due to incorrect baseChar offset
2015-07-30 ChorusTextClient - added basic socket.io connection code
2015-07-31 ChorusTextServer - minor fix on device retrieving text from server, and also for socket room/session connections
    [ChorusTextClient.js]
